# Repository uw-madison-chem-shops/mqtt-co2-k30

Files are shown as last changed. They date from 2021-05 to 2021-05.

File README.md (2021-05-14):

# MQTT CO2 K30

Simple project to get [K30 CO2 sensors](https://www.co2meter.com/products/k-30-co2-sensor-module) online using MQTT.

Designed to work with [mqtt.chem.wisc.edu](https://mqtt.chem.wisc.edu/).

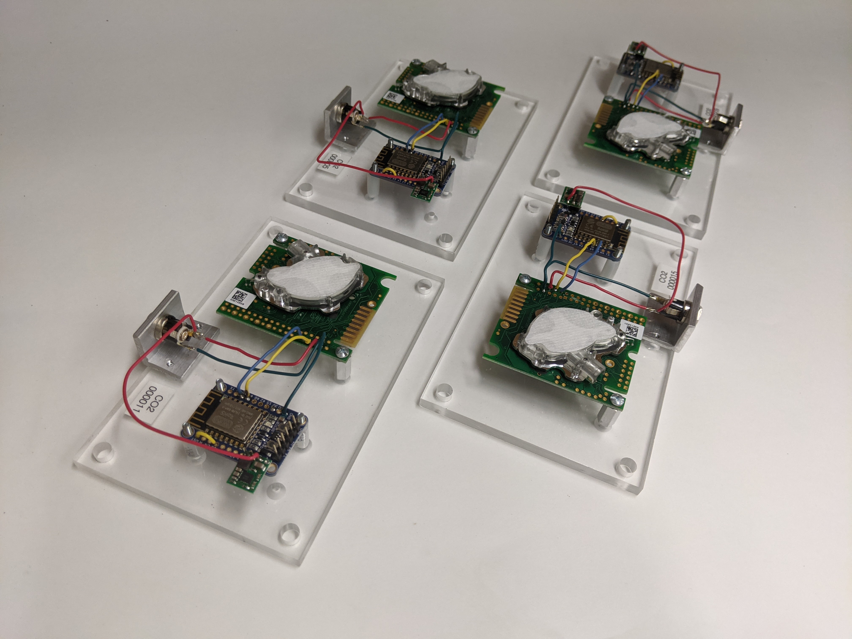
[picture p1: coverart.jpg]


## Repository

This is an open source hardware project licensed under the CERN Open Hardware Licence Version 2 - Permissive.
Please see the LICENSE file for the complete license.

This repository is being mirrored to several version control systems in an attempt to ensure maximum avaliability.

| name | url |
| --- | --- |
| GitHub (primary) | https://github.com/uw-madison-chem-shops/mqtt-co2-k30 |
| GitLab | https://gitlab.com/uw-madison-chem-shops/mqtt-co2-k30 |

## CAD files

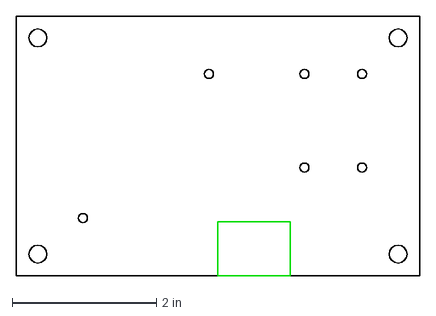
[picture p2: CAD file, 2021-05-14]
mounting-plate/mounting-plate.dxf
5.60 x 3.60 in

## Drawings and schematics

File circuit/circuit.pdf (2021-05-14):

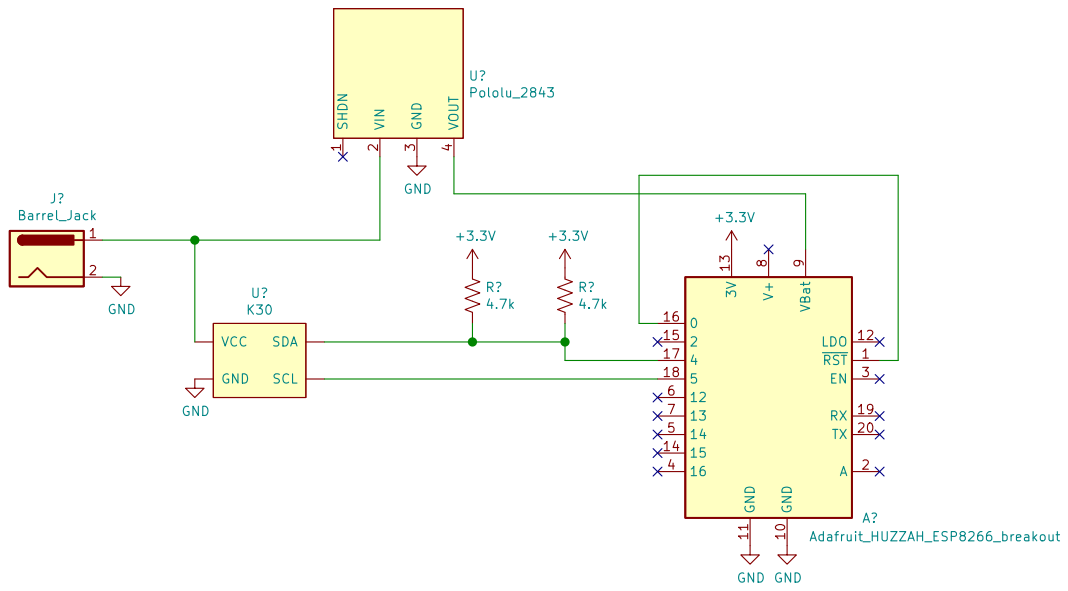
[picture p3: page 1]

4 U?Pololu_2843 GND SCL VCC SDA U? GND K30

bthompson@chem.wisc.edu R?

Blaise Thompson
Bertram Group
Department of Chemistry
Id: 1/1 Title: CO2 Sensor File: circuit.sch Sheet: / University of Wisconsin-Madison

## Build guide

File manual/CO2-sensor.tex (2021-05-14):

\documentclass{manual}
\pagenumbering{gobble}

\usepackage{listings}

\title{MQTT CO2 Sensor}
\author{Blaise J Thompson}

\begin{document}

\maketitle

\vspace*{\fill}



\vspace*{\fill}

\section{Description}
\pagenumbering{arabic}

This manual documents the construction and development of the wireless, distributed CO2 sensor project.
These WiFi-enabled sensors broadcast data via \href{https://mqtt.org/}{MQTT}.

\section{Wiring}

\subsection{Bill of Materials}

\begin{itemize}
  \item CO2 sensor (CO2METER.COM K30 - \$85)
  \item microcontroller (Adafruit ``Huzzah'' 2471 - \$10)
  \item 5 V regulator (Pololu 2843 - \$5)
  \item barrel jack (Switchcraft 722A - \$2)
  \item 2x 4.7k$\Omega$, 0.25 W resistors
  \item barrel jack holder, polycarbonate mounting plate (homemade)
\end{itemize}

\subsection{Wiring}

Wiring is pretty simple, you can see all of it here.
Note that the two pull-up resistors are underneith the micro-controller.
The HUZZAH break-out board has awkwardly small mounting holes, so we ended up using M2 screws.



\includepdf[landscape=true]{../circuit/circuit.pdf}

\subsection{Power Considerations}

9-14 V input power (2.1 mm barrel, center positive).

32 hours battery life with 6 AA.

\section{Firmware}

This section describes the firmware that was flashed to the ESP8266 microcontroller.
This project was built on-top of the open-source microhomie firmware, in particular microhomie-esp8266-v2.4.0-beta1. \\
The pre-compiled binary can be downloaded from GitHub: \\
\url{https://github.com/microhomie/microhomie/releases/tag/v3.0.0-beta1}.

\subsection{main}

main.py is automatically run by micropython when the controller initializes.
In this case, we create a single HomieDevice and run it forever.
Note that microhomie uses uasyncio to enable async-await syntax in micropython.

\includepython{../firmware/main.py}

\clearpage
\subsection{settings}

microhomie automatically reads configuration details from a file called ``settings.py''.
Some values have been redacted as, unfortunately, login credentials for the private network cannot be shared.

\includepython{../firmware/settings.redacted.py}

\subsection{flash}

The following bash script was used to flash the microcontroller.
Importantly, the ID field must be changed for each device before flashing.
This flash script uses \href{https://github.com/espressif/esptool}{esptool} and \href{https://github.com/scientifichackers/ampy}{ampy}, both python utilities.
Blaise also recommends \href{https://github.com/dhylands/rshell}{rshell} for debugging the microcontroller, including remote REPL and incremental file transfer.

\includebash{../firmware/flash.sh}

\section{Server}

These devices are, of course, able to publish to any MQTT broker as configured in firmware.
In this case, they have been programmed to publish to \url{https://mqtt.chem.wisc.edu}.
This server also runs a database application with a little bit of custom Python to link things together.
All of this runs using Docker.
See the git repository at \url{https://git.chem.wisc.edu/infrastructure/mqtt} for complete documentation of how this server is put together.

You may interact with the server in several different ways.
These are documented on the website.

\end{document}

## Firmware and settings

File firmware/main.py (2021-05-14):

import settings

import sys
import machine
from machine import Pin, I2C
import network
import time
import struct

import mqtt_as
mqtt_as.MQTT_base.DEBUG = True

from homie.constants import FALSE, TRUE, BOOLEAN, FLOAT, STRING
from homie.device import HomieDevice
from homie.node import HomieNode
from homie.property import HomieNodeProperty
from uasyncio import get_event_loop, sleep_ms


def read_co2():
    for _ in range(10):
        try:
            i2c = I2C(scl=Pin(4), sda=Pin(5), freq=10000)
            i2c.writeto(104, "\x22\x00\x08\x2A".encode())
            time.sleep_ms(100)
            out = i2c.readfrom(104, 4)
            out = struct.unpack(">h", out[1:3])[0]
            return out
        except Exception as e:
            time.sleep_ms(250)
            print(e)


class K30(HomieNode):
    def __init__(self, name="k30", device=None):
        super().__init__(id="k30", name=name, type="sensor")
        self.device = device
        self.co2 = HomieNodeProperty(
            id="co2", name="co2", unit="ppm", settable=False, datatype=FLOAT, default=0,
        )
        self.add_property(self.co2)
        self.uptime = HomieNodeProperty(
            id="uptime", name="uptime", settable=False, datatype=STRING, default="PT0S"
        )
        self.add_property(self.uptime)
        loop = get_event_loop()
        loop.create_task(self.update_data())
        loop.create_task(self.reset())
        self.led = Pin(0, Pin.OUT)
        self.start = time.time()
        self.last_onine = 0

    async def reset(self):
        await sleep_ms(5 * 60 * 1000)   # 5 minutes
        machine.reset()

    async def update_data(self):
        # wait until connected
        for _ in range(60):
            await sleep_ms(1_000)
            if self.device.mqtt.isconnected():
                break
        # loop forever
        while self.device.mqtt.isconnected():
            self.last_onine = time.time()
            self.led.value(0)  # on
            self.co2.data = read_co2()
            self.uptime.data = self.get_uptime()
            self.led.value(1)  # on
            await sleep_ms(5000)
        while not self.device.mqtt.isconnected():
            self.led.value(0)  # illuminate onboard LED
            await sleep_ms(100)
            self.led.value(1)  # onboard LED off
            await sleep_ms(1000)

    def get_uptime(self):
        diff = int(time.time() - self.start)
        out = "PT"
        # hours
        if diff // 3600:
            out += str(diff // 3600) + "H"
            diff %= 3600
        # minutes
        if diff // 60:
            out += str(diff // 60) + "M"
            diff %= 60
        # seconds
        out += str(diff) + "S"
        return out


def main():
    # homie
    homie = HomieDevice(settings)
    homie.add_node(K30(device=homie))
    homie.run_forever()


if __name__ == "__main__":
    main()
